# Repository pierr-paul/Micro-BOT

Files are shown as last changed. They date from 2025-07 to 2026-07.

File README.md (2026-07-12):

# Micro'BOT

<p align="justify">
<strong>Micro'BOT est un robot éducatif open-source, conçu pour l'enseignement et l'expérimentation des concepts algorithmiques dans le cadre du programme de Numérique et Sciences Informatiques (NSI).</strong>
</p>

<br>

<p align="center">
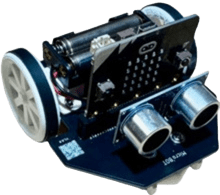
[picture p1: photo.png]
Photo du Micro'BOT
  
</p>

<br>

### Contexte du projet

<p align="justify">
Ce robot a été entièrement conçu et fabriqué dans le cadre d'un mémoire de Master MEEF NSI intitulé <strong>« Robots éducatifs et concepts algorithmiques : vers une meilleure motivation et une compréhension renforcée chez les élèves »</strong>.
</p>

<p align="justify">
L'objectif de ce travail de recherche est d'étudier l'impact de l'interaction avec un robot sur la motivation des élèves à apprendre les concepts algorithmiques. En s'appuyant sur les principes du <strong>constructivisme</strong> (Seymour Papert), le Micro'BOT a été pensé comme un médiateur tangible entre la théorie et la pratique. Il permet de matérialiser des abstractions logiques (boucles, conditions, séquençage) en actions physiques observables, transformant l'apprentissage en une expérience concrète et motivante.
</p>

<p align="justify">
La création d'un robot « sur mesure » plutôt que l'utilisation d'une solution commerciale répond à un double enjeu :
</p>

1.  **maîtriser l'outil expérimental** pour les besoins de la recherche.
2.  **garantir la reproductibilité de la recherche** en proposant une solution entièrement open-source et à faible coût.

### Description technique

Le Micro'BOT est une plateforme simple et modulaire :
-   le « cerveau » du robot est une carte **micro:bit** ;
-   le châssis, les fixations et les roues sont imprimés en 3D ;
-   une carte électronique s'interface avec la carte micro:bit pour piloter les moteurs et les capteurs.

### Programmation

Le robot peut être programmé avec **Microsoft MakeCode** : [https://makecode.microbit.org](https://makecode.microbit.org)

### Contenu du dépôt

Ce dépôt contient l'ensemble des fichiers nécessaires à la fabrication du Micro'BOT :

*   **`README.md`** : ce fichier de présentation.
*   **`LICENSE`** : la licence MIT du projet.
*   **`carte.sch`, `carte.brd`** : les fichiers de conception de la carte électronique (schéma et circuit imprimé) pour le logiciel Autodesk Eagle.
*   **`fixation r....stl` (plusieurs fichiers)** : les fichiers STL pour l'impression 3D des différentes pièces du châssis.
*   **`jante.stl`, `roulette....stl`** : les fichiers STL pour l'impression 3D des roues.
*   **`JLCPCB.zip`** : l'archive contenant les fichiers Gerber pour une commande professionnelle du circuit imprimé (PCB).
*   **`pxt.json`, `extension.ts`** : les fichiers de configuration pour l'extension Microsoft MakeCode.
*   **`actifs`, `classeur.xlsx`, `aide.txt`, `photo.png`, `.gitignore`** : les fichiers de configuration et ressources du projet.

### Licence
<p align="justify">
Ce projet est distribué sous la <strong>licence MIT</strong>. Vous êtes libre de l'utiliser, de le modifier et de le partager.
</p>

### Auteur
*   **M. Pierre PAUL**, dans le cadre du Master MEEF NSI (2024-2026) à l'INSPÉ de Lorraine - Université de Lorraine.
*   Sous la direction de **MM. David LANGLOIS et Alexis SCHEUER**.

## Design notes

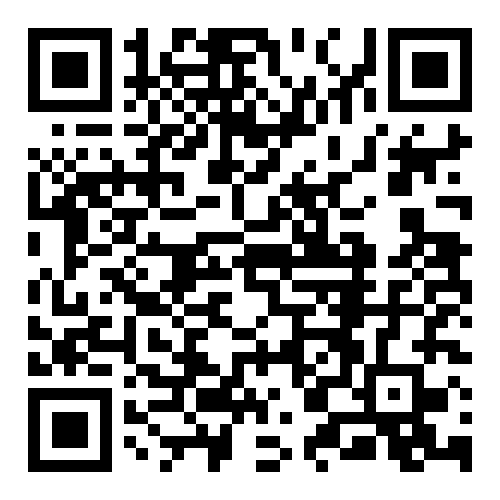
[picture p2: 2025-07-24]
actifs/lien URL GitHub.bmp

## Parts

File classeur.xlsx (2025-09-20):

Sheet: Informations
Nom du produit | Référence | Lien WEB
Micro'BOT

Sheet: Nomenclature
Référence interne | Nom de la pièce / Composant | Catégorie (Électronique, Mécanique, Logiciel, Emballage, etc.) | Description / Spécifications techniques | Unité de mesure | Quantité par produit | Fournisseur | Lien WEB | Référence fournisseur | Coefficient d'approvisionnement | Coût unitaire (€) | Coût total par produit (€) | Délai d’approvisionnement (jours) | Lieu de stockage interne | Version / Révision | Statut (Validé, En test, Obsolète, etc.) | Remarques / Notes
 | Carte Micro:bit | Électronique |  | Pièce | 1 | AliExpress | www.aliexpress.com (https://www.aliexpress.com/item/1005008717477400.html) |  |  |  |  |  |  |  | Validé
 | Carte électronique | Électronique |  | Pièce | 1 | JLCPCB |  |  | 2 |  |  | 14 |  |  | Validé
 | Capteur HC-SR04 3V | Électronique |  | Pièce | 1 | AliExpress | www.aliexpress.com (https://fr.aliexpress.com/item/1005007252904201.html?mp=1) |  |  |  |  |  |  |  | Validé
 | Capteur IRT20001/T | Électronique |  | Pièce | 2 | AliExpress | www.aliexpress.com (https://www.aliexpress.com/item/1005007811078572.html) |  |  |  |  |  |  |  | Validé
 | Interrupteur K028C005-G5 | Électronique |  | Pièce | 1 | AliExpress | www.aliexpress.com (https://www.aliexpress.com/item/1005009260366850.html) |  |  |  |  |  |  |  | Validé
 | Motoréducteur 3V 200 RPM | Électronique |  | Pièce | 2 | AliExpress | www.aliexpress.com (https://www.aliexpress.com/item/1005007573764916.html) |  |  |  |  |  |  |  | Validé
 | Connecteur pour carte | Électronique |  | Pièce | 1 | AliExpress | www.aliexpress.com (https://www.aliexpress.com/item/1005005495859698.html) |  |  |  |  |  |  |  | Validé
 | Barrette femelle 4P pas 2,54 mm | Électronique |  | Pièce | 1 | AliExpress | www.aliexpress.com (https://www.aliexpress.com/item/1005007414089348.html) |  |  |  |  |  |  |  | Validé
 | Pile AAA alcaline 1,5V rechargeable | Électronique |  | Pièce | 2 | AliExpress | www.aliexpress.com (https://www.aliexpress.com/item/1005009484101009.html) |  |  |  |  |  |  |  | Validé
 | Coupleur de 2 piles AAA câblé en silicone | Électronique |  | Pièce | 1 | AliExpress | www.aliexpress.com (https://www.aliexpress.com/item/1005004825120572.html) |  |  |  |  |  |  |  | Validé
 | Chargeur pour piles AAA alcaline 1,5V | Électronique |  | Pièce | 1 | AliExpress | www.aliexpress.com (https://fr.aliexpress.com/item/1005008672655436.html) |  |  |  |  |  |  |  | Validé
 | Boîte de rangement pour 10 piles AAA | Divers |  | Pièce | 1 | AliExpress | www.aliexpress.com (https://www.aliexpress.com/item/1005005486517591.html) |  |  |  |  |  |  |  | Validé | Pour 1 à 5 robots
 | Pièce imprimée en 3D | Mécanique |  | Lot | 1 | JLC3DP |  |  |  |  |  | 14 |  |  | Validé
 | Vis M2 x 6 mm avec rondelle | Mécanique |  | Pièce | 4 | AliExpress | www.aliexpress.com (https://www.aliexpress.com/item/1005009278678683.html) |  |  |  |  |  |  |  | Validé
 | Vis M3 x 5 mm avec rondelle | Mécanique |  | Pièce | 2 | AliExpress | www.aliexpress.com (https://www.aliexpress.com/item/1005009278678683.html) |  |  |  |  |  |  |  | Validé
 | Écrou bloquant M2 | Mécanique |  | Pièce | 4 | AliExpress | www.aliexpress.com (https://www.aliexpress.com/item/1005008280044118.html) |  |  |  |  |  |  |  | Validé
 | Insert M3 (Ø extérieur 4,5 mm, longueur 4,5 mm) | Mécanique |  | Pièce | 2 | AliExpress | www.aliexpress.com (https://www.aliexpress.com/item/1005007921829413.html) |  |  |  |  |  |  |  | Validé
 | Caoutchouc anneau plat noir (40 × 5 × 1,5 mm) | Mécanique |  | Pièce | 2 | AliExpress | www.aliexpress.com (https://www.aliexpress.com/item/1005008264682781.html) |  |  |  |  |  |  |  | Validé
 | Câble USB A/C vers Micro USB (25 cm) | Électronique |  | Pièce | 1 | AliExpress | www.aliexpress.com (https://www.aliexpress.com/item/1005009509127695.html) |  |  |  |  |  |  |  | Validé
 | Câble silicone rouge et noir (paire, 26 AWG) | Électronique |  | Mètre | 0.06 | AliExpress | www.aliexpress.com (https://www.aliexpress.com/item/1005007213319794.html) |  |  |  |  |  |  |  | Validé
 | Clé USB 4 GB A/C noir | Électronique |  | Pièce | 1 | AliExpress | www.aliexpress.com (https://www.aliexpress.com/item/1005007775077453.html) |  |  |  |  |  |  |  | Validé
 | Étiquettes 60 × 30 mm | Divers |  | Pièce | 1 | AliExpress | www.aliexpress.com (https://fr.aliexpress.com/item/1005006549356447.html?scm_id=1007.40050.354490.0&scm-url=1007.40050.354490.0) |  |  |  |  |  |  |  | Validé
 | Étiquettes 25 × 15 mm | Divers |  | Pièce | 1 | AliExpress | www.aliexpress.com (https://fr.aliexpress.com/item/1005002129924144.html?curPageLogUid=yR1PYmnFVWOe) |  |  |  |  |  |  |  | Validé
 | Scotch double face 15 × 1 mm | Divers |  | Mètre | 0.05 | AliExpress | www.aliexpress.com (https://www.aliexpress.com/item/1005007436373927.html) |  |  |  |  |  |  |  | Validé
 | Boîte de rangement | Divers |  | Pièce | 1 | AliExpress | www.aliexpress.com (https://www.aliexpress.com/item/1005006880830763.html) |  |  |  |  |  |  |  | Validé | Pour 1 à 5 robots et accessoires
 | Cadenas | Divers | Code par défaut : 000 | Pièce | 1 | AliExpress | www.aliexpress.com (https://www.aliexpress.com/item/1005009619676043.html?mp=1) |  |  |  |  |  |  |  | Validé
 | Caoutchouc naturel (38 × 1 × 1 mm) | Divers |  | Pièce | 1 | AliExpress | www.aliexpress.com (https://www.aliexpress.com/item/33016091366.html) |  |  |  |  |  |  |  | Validé
 | Sachet de silice | Divers |  | Pièce | 1 | AliExpress | www.aliexpress.com (https://fr.aliexpress.com/item/1005007122286887.html?curPageLogUid=dR0MWqSR1oRP) |  |  |  |  |  |  |  | Validé

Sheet: Fournisseurs
Nom du fournisseur | Contact | Adresse | Téléphone | E-mail | Site web | Conditions de paiement | Délai moyen de livraison (jours) | Notes
AliExpress |  |  |  |  | www.aliexpress.com |  | 10
JLCPCB |  |  |  |  | www.jlcpcb.com |  | 14
JLC3DP |  |  |  |  | www.jlc3dp.com |  | 14

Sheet: Coûts de production
Poste de coût | Description | Unité | Quantité | Coût unitaire (€) | Coût total (€) | Commentaires
Matières premières | Composants mécaniques et électroniques
Emballage | Boîte, protections, inserts | Pièce | 1
Notice | Impression de la documentation utilisateur
Main d'œuvre | Temps de montage du produit | Heure | 1
Tests qualité | Contrôle et validation du produit
Transport | Expédition au client
Électricité
Consommables
Ateliers

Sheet: Approvisionnement
Référence interne | Nom de la pièce | Fournisseur | Quantité nécessaire | Stock actuel | Quantité à commander | Date de commande | Date de livraison prévue | Statut

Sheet: Révisions du produit
Version | Date | Modifications apportées | Responsable | Commentaires
1.0.0 | 01.08.25

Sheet: Vente
Taux de marge | Quantité | Réduction | Prix de vente TTC (€)

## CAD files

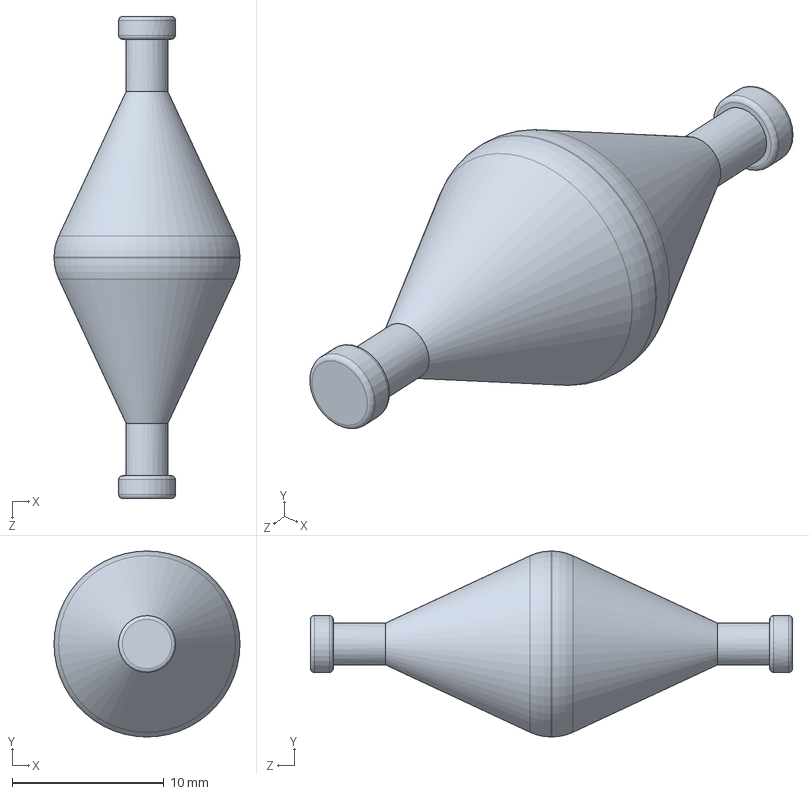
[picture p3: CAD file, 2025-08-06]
roulette.SLDPRT
12.2 x 12.2 x 31.8 mm

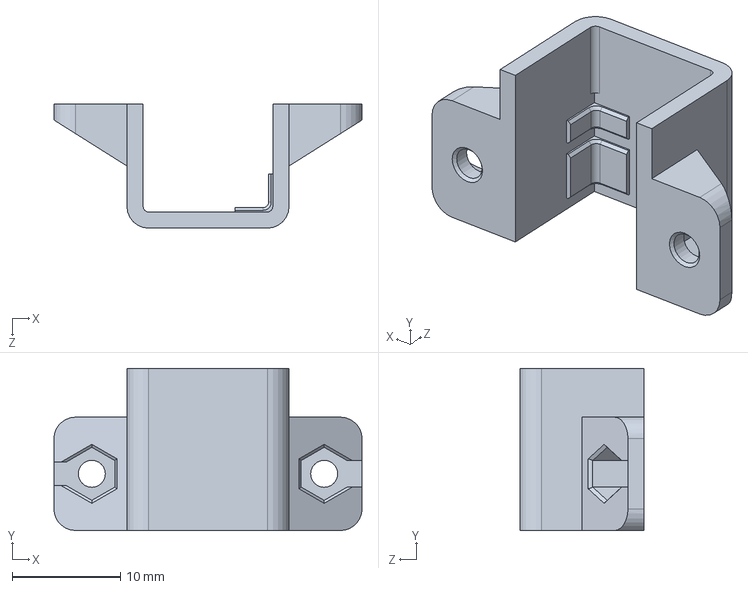
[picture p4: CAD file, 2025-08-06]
fixation motoréducteur.SLDPRT
28.5 x 15.0 x 11.5 mm

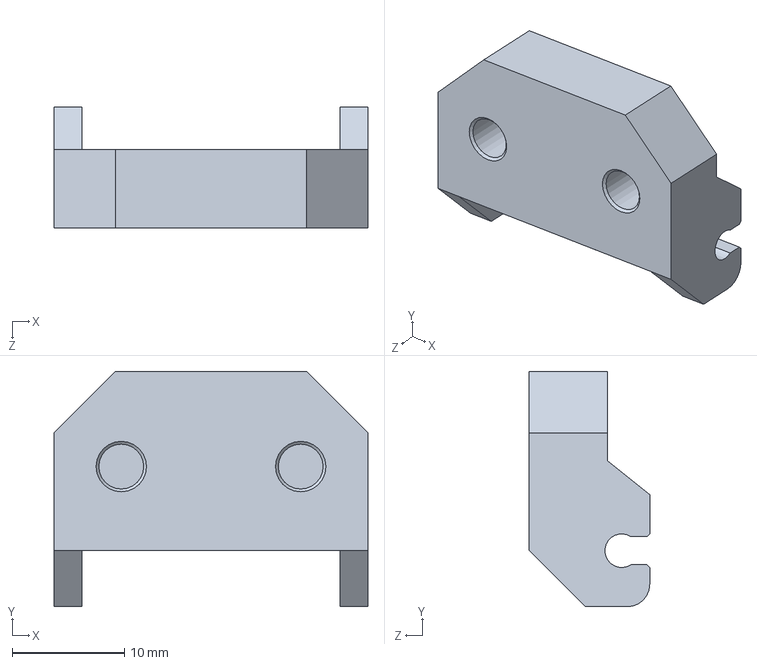
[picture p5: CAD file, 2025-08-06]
fixation roulette.SLDPRT
28.0 x 21.0 x 10.8 mm

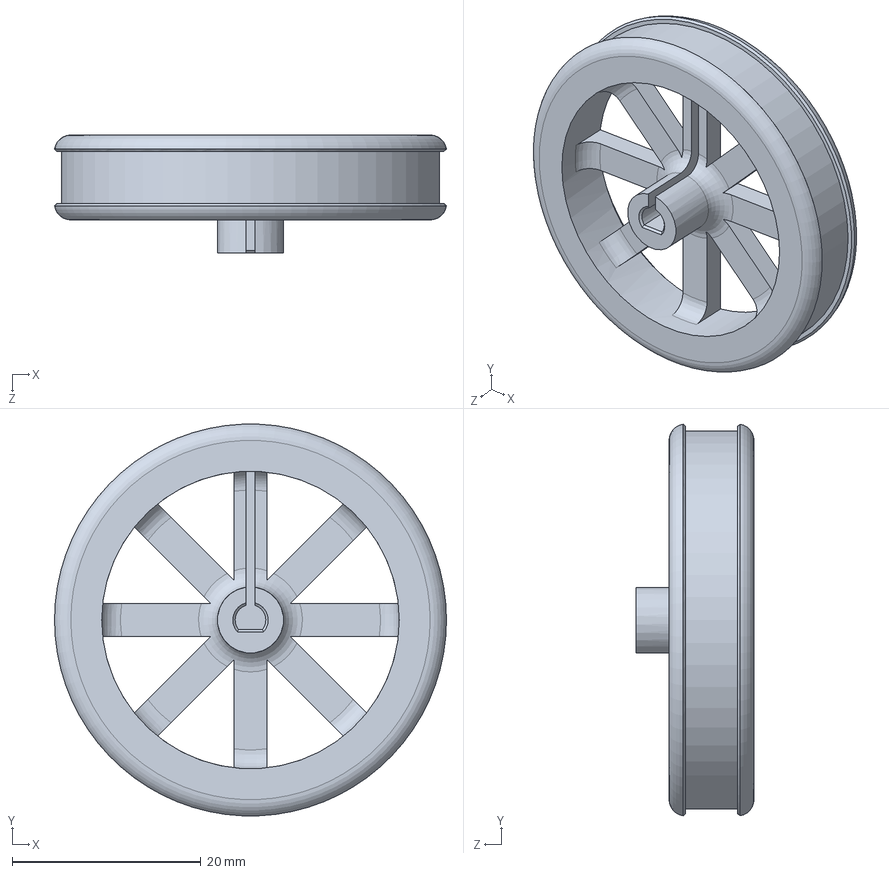
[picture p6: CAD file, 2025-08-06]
jante.SLDPRT
41.5 x 41.5 x 12.5 mm

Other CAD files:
fixation motoréducteur.STL
fixation roulette.stl
jante.stl
roulette.STL

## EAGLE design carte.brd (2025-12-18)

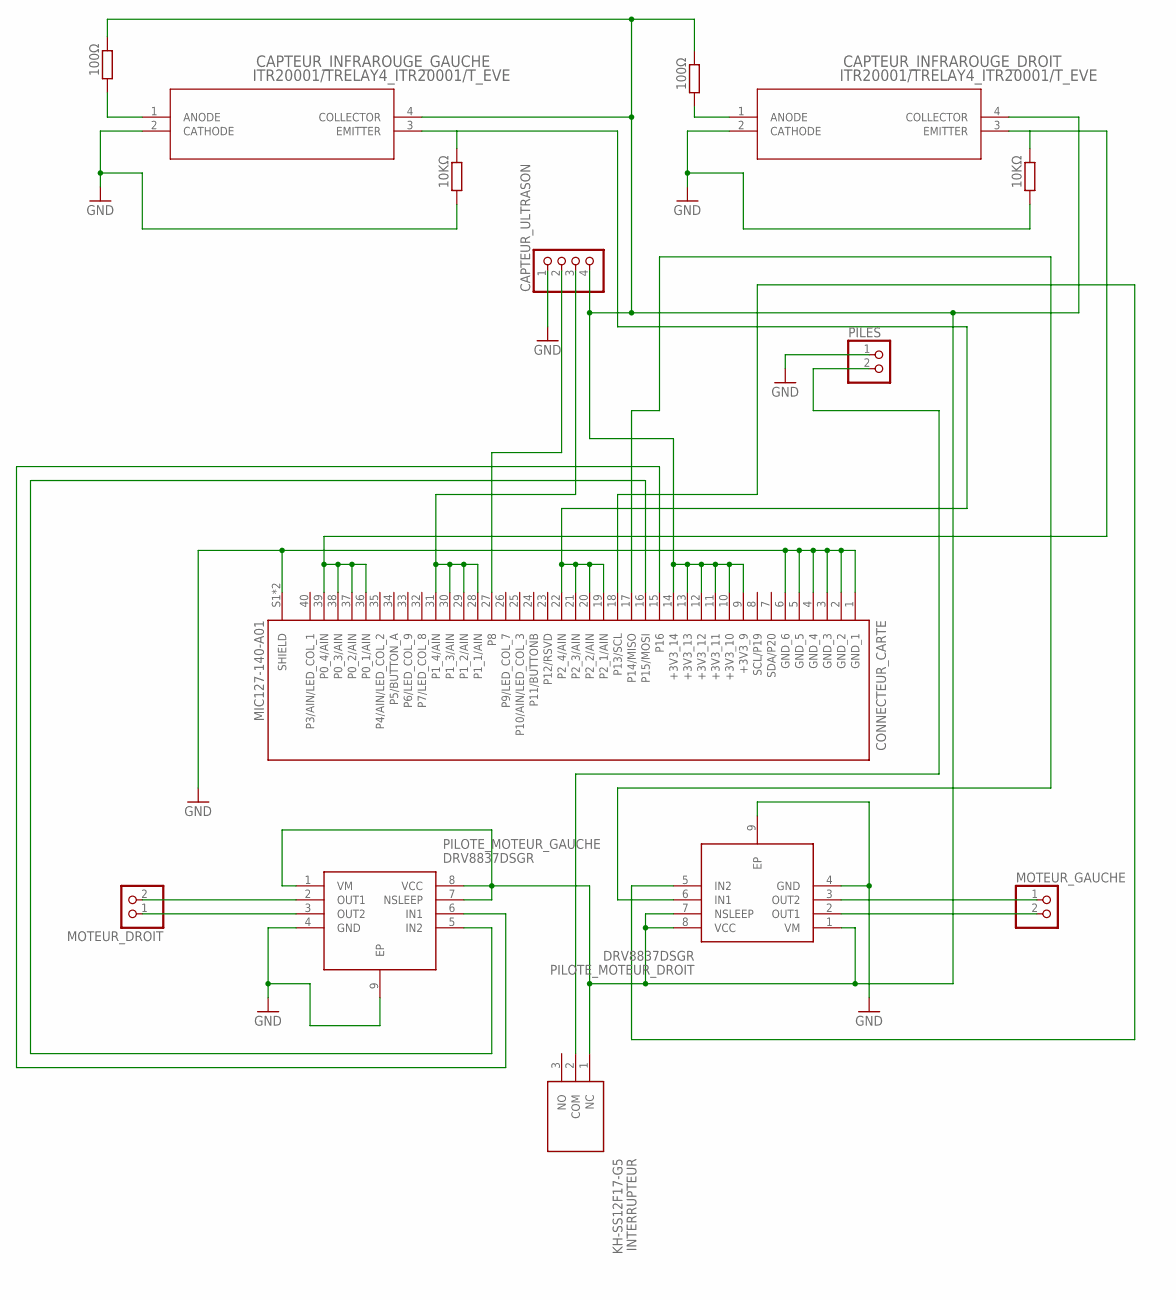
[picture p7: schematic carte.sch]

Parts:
CAPTEUR_INFRAROUGE_DROIT: ITR20001/TRELAY4_ITR20001/T_EVE; RELAY4_ITR20001/T_EVE; LCSC C264269
CAPTEUR_INFRAROUGE_GAUCHE: ITR20001/TRELAY4_ITR20001/T_EVE; RELAY4_ITR20001/T_EVE; LCSC C264269
CAPTEUR_ULTRASON: PINHD-1X4; 1X04
CONNECTEUR_CARTE: MIC127-140-A01; DONGGUAN_MIC127-140-A01; LCSC C5154027
INTERRUPTEUR: KH-SS12F17-G5; KHSS12F17G5; LCSC C5274464
MOTEUR_DROIT: PINHD-1X2; 1X02
MOTEUR_GAUCHE: PINHD-1X2; 1X02
PILES: PINHD-1X2; 1X02
PILOTE_MOTEUR_DROIT: DRV8837DSGR; SON50P200X200X80-9N; LCSC C39159
PILOTE_MOTEUR_GAUCHE: DRV8837DSGR; SON50P200X200X80-9N; LCSC C39159
R1, R3: 10KΩ; R0603; LCSC C25804
R2, R5: 100Ω; R0603; LCSC C22775

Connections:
3V: CAPTEUR_INFRAROUGE_DROIT.4 (COLLECTOR), CAPTEUR_INFRAROUGE_GAUCHE.4 (COLLECTOR), CAPTEUR_ULTRASON.4, CONNECTEUR_CARTE.9 (+3V3_9), CONNECTEUR_CARTE.10 (+3V3_10), CONNECTEUR_CARTE.11 (+3V3_11), CONNECTEUR_CARTE.12 (+3V3_12), CONNECTEUR_CARTE.13 (+3V3_13), CONNECTEUR_CARTE.14 (+3V3_14), INTERRUPTEUR.1 (NC), PILOTE_MOTEUR_DROIT.1 (VM), PILOTE_MOTEUR_DROIT.7 (NSLEEP), PILOTE_MOTEUR_DROIT.8 (VCC), PILOTE_MOTEUR_GAUCHE.1 (VM), PILOTE_MOTEUR_GAUCHE.7 (NSLEEP), PILOTE_MOTEUR_GAUCHE.8 (VCC), R2.1, R5.1
GND: CAPTEUR_INFRAROUGE_DROIT.2 (CATHODE), CAPTEUR_INFRAROUGE_GAUCHE.2 (CATHODE), CAPTEUR_ULTRASON.1, CONNECTEUR_CARTE.1 (GND_1), CONNECTEUR_CARTE.2 (GND_2), CONNECTEUR_CARTE.3 (GND_3), CONNECTEUR_CARTE.4 (GND_4), CONNECTEUR_CARTE.5 (GND_5), CONNECTEUR_CARTE.6 (GND_6), CONNECTEUR_CARTE.S1 (SHIELD), CONNECTEUR_CARTE.S2 (SHIELD), PILES.1, PILOTE_MOTEUR_DROIT.4 (GND), PILOTE_MOTEUR_DROIT.9 (EP), PILOTE_MOTEUR_GAUCHE.4 (GND), PILOTE_MOTEUR_GAUCHE.9 (EP), R1.2, R3.2
unnamed: MOTEUR_DROIT.2, PILOTE_MOTEUR_GAUCHE.2 (OUT1)
unnamed: MOTEUR_DROIT.1, PILOTE_MOTEUR_GAUCHE.3 (OUT2)
unnamed: MOTEUR_GAUCHE.1, PILOTE_MOTEUR_DROIT.3 (OUT2)
unnamed: MOTEUR_GAUCHE.2, PILOTE_MOTEUR_DROIT.2 (OUT1)
unnamed: CAPTEUR_INFRAROUGE_GAUCHE.1 (ANODE), R5.2
unnamed: INTERRUPTEUR.2 (COM), PILES.2
unnamed: CAPTEUR_INFRAROUGE_DROIT.1 (ANODE), R2.2
P0: CAPTEUR_INFRAROUGE_DROIT.3 (EMITTER), CONNECTEUR_CARTE.36 (P0_1/AIN), CONNECTEUR_CARTE.37 (P0_2/AIN), CONNECTEUR_CARTE.38 (P0_3/AIN), CONNECTEUR_CARTE.39 (P0_4/AIN), R3.1
P1: CAPTEUR_ULTRASON.3, CONNECTEUR_CARTE.28 (P1_1/AIN), CONNECTEUR_CARTE.29 (P1_2/AIN), CONNECTEUR_CARTE.30 (P1_3/AIN), CONNECTEUR_CARTE.31 (P1_4/AIN)
P2: CAPTEUR_INFRAROUGE_GAUCHE.3 (EMITTER), CONNECTEUR_CARTE.19 (P2_1/AIN), CONNECTEUR_CARTE.20 (P2_2/AIN), CONNECTEUR_CARTE.21 (P2_3/AIN), CONNECTEUR_CARTE.22 (P2_4/AIN), R1.1
P8: CAPTEUR_ULTRASON.2, CONNECTEUR_CARTE.27 (P8)
P13: CONNECTEUR_CARTE.18 (P13/SCL), PILOTE_MOTEUR_DROIT.5 (IN2)
P14: CONNECTEUR_CARTE.17 (P14/MISO), PILOTE_MOTEUR_DROIT.6 (IN1)
P15: CONNECTEUR_CARTE.16 (P15/MOSI), PILOTE_MOTEUR_GAUCHE.5 (IN2)
P16: CONNECTEUR_CARTE.15 (P16), PILOTE_MOTEUR_GAUCHE.6 (IN1)

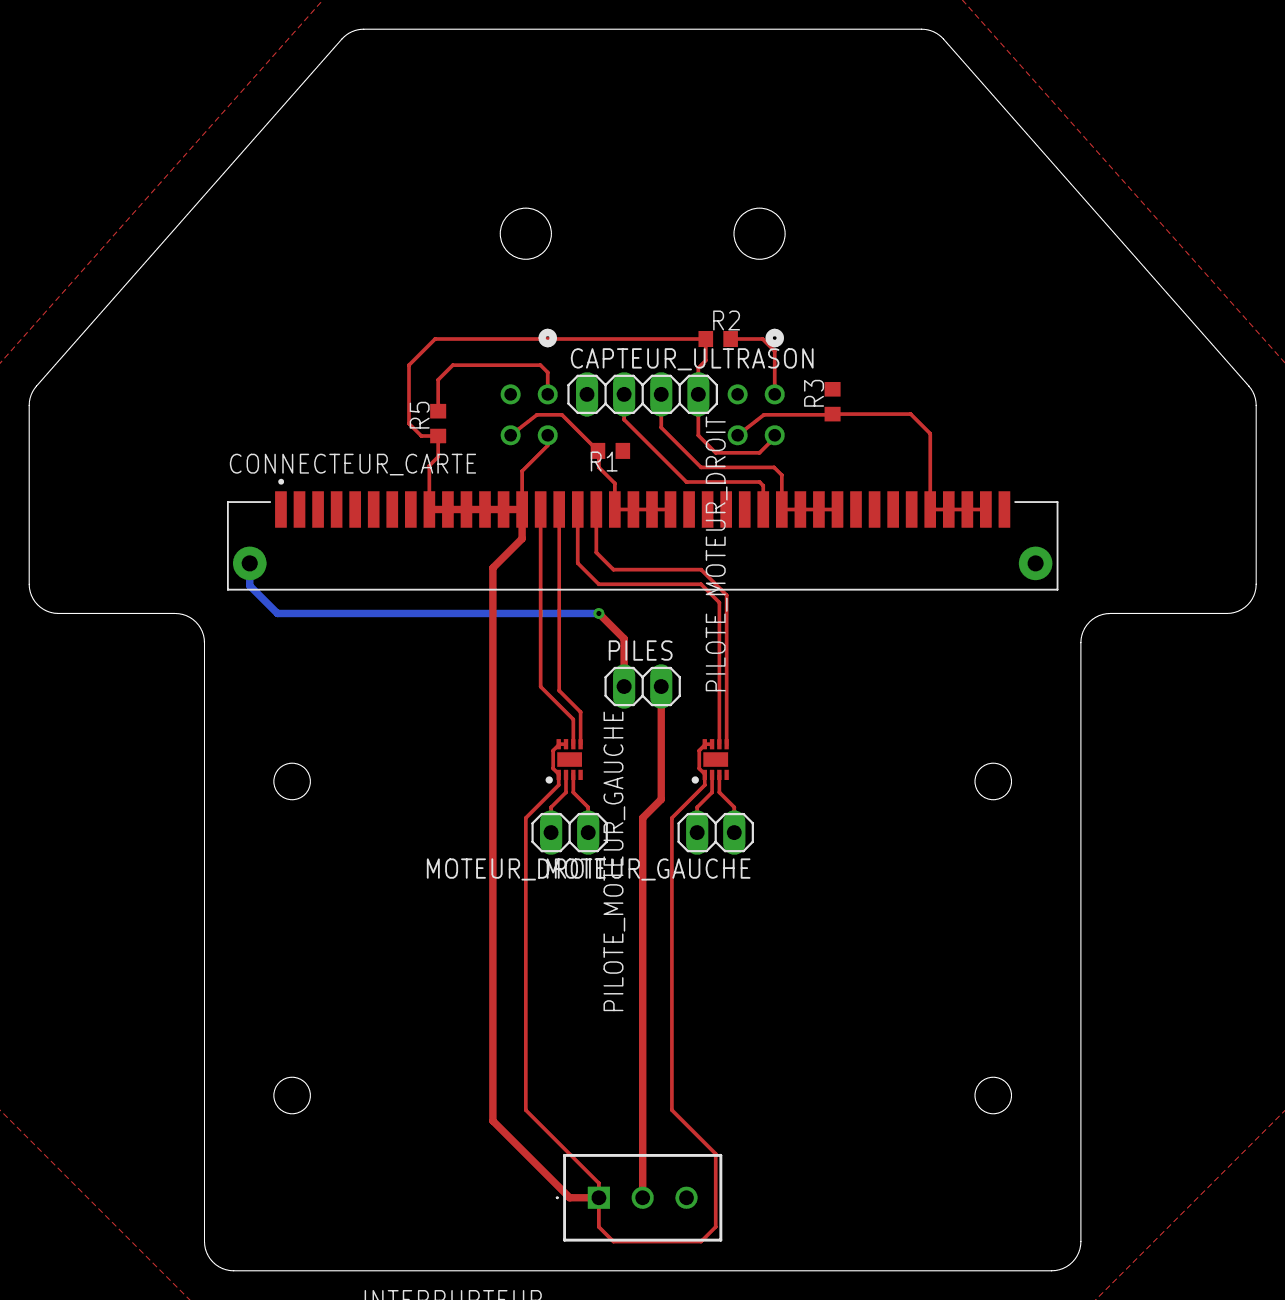
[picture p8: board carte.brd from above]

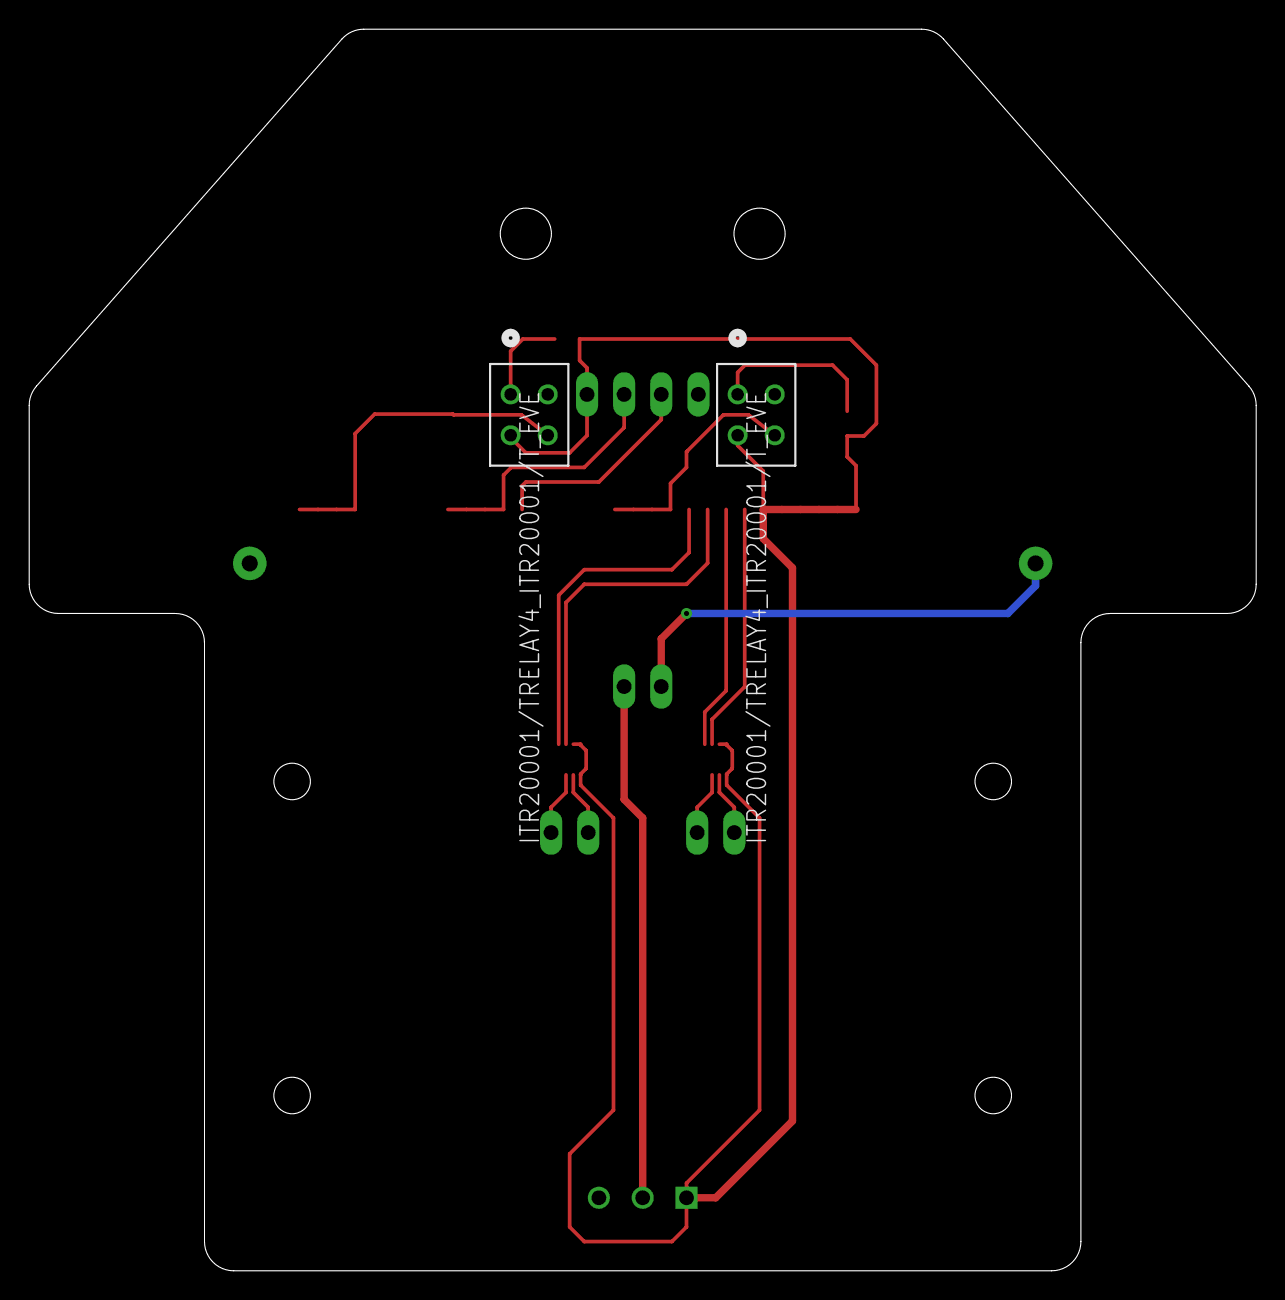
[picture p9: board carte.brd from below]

Board: 2 copper layers, 84.0 x 85.0 mm, 14 parts (2 on the bottom side), 17 nets.
